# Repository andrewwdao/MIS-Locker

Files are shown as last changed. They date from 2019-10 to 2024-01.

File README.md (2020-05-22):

# SOURCE CODE FOR MIS-CTU LOCKER

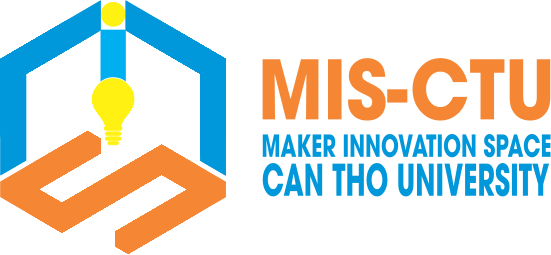
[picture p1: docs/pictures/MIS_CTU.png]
MIS-CTU logo (https://mis.ctu.edu.vn/)


System code for MIS-CTU Locker system. Designed for [Raspberry Pi](https://en.wikipedia.org/wiki/Raspberry_Pi) based devices.
Tested on Raspberry Pi 3B+.



 <!-- [![License](https://img.shields.io/github/license/minhan74/MIS-Locker.svg)](LICENSE) -->


## Documentation

* **[User guide]**: Show user on how to use the locker.
* **[Admin guide]**: Guidance for admin, how to further configurate the software, or further develop it.
* **[Software Installation]**: How to flash Rasbian and install the system.
* **[Hardware Documentation]**: Documents about PCB, electronics components,...
* **[Undergrad Thesis Report]**: A part of this project is also my undergraduate thesis, you can have a look of it here. (in Vietnamese)

## Credited libraries

* [Python3-fingerprint], (c) 2016 Bastian Raschke. Licensed under the German Free Software License
* [Adafruit CircuitPython ADS1x15], (c) 2017 Carter Nelson for Adafruit Industries. Licensed under the MIT License.
* [pySerial], (c) 2001 - 2017 Chris Liechti <cliechti@gmx.net>. Licensed under the BSD Liscense.
* [smbus],(c) 2015 - 2017 Pimoroni Ltd.
* [smbus2], (c) 2017 - 2019 Karl-Petter Lindegaard. Licensed under the MIT License.
* [RPi.GPIO], (c) 2012 - 2019 Ben Croston. Licensed under the MIT License.
* [wiringPi], (c) 2013 - 2019 Gordon <projects@drogon.net>.
* [Flask], (c) 2010 Pallets. Licensed under the BSD 3-Clause Liscense
* [WTForm], (c) 2008 by the WTForms team. Licensed under the BSD Liscense.
* [SQLAlchemy], (c) 2005 - 2020 SQLAlchemy authors and contributors. Licensed under the MIT License.
* [Flask-Migrate], (c) 2013 Miguel Grinberg. Licensed under the MIT License.
* [Flask-Bootstrap], (c) 2013 - 2019 Marc Brinkmann. Licensed under the BSD 3-Clause Liscense.
* [Readonly], (c) 2017 - 2019 Ways. Licensed under the GNU License.
* [Gevent], (c) 2015 - 2020 Denis Bilenko, Jason Madden. Licensed under the MIT License.

 _And the contribution of the huge open-source community world wide._

**Made for Maker Innovation Space, Can Tho University, Can Tho, Vietnam (MIS-CTU).**

## Sponsors

CTU small (https://ctu.edu.vn/)
MIS-CTU small (https://mis.ctu.edu.vn/)
URI small (https://sites.google.com/asu.edu/uri-coordinator-resources/uri-research-symposium/)
Konel small (https://konel.jp/)

_(c) 2019 - 2020 [Minh-An Dao] - Minh-Luan Nguyen_
_Licensed under the MIT License. All rights reserved._

<!-- Links -->
[User guide]: /docs/User_guide.md
[Admin guide]: /docs/Admin_guide.md
[Software Installation]: /docs/Installation.md
[Software Configuration]: /docs/Configuration.md
[Hardware Documentation]: /docs/Hardware-Documentation.md
[Undergrad Thesis Report]: https://bit.ly/DMA_Undergrad

[Python3-fingerprint]: https://github.com/bastianraschke/pyfingerprint
[Adafruit CircuitPython ADS1x15]: https://github.com/adafruit/Adafruit_CircuitPython_ADS1x15
[pySerial]: https://github.com/pyserial/pyserial
[smbus]: https://github.com/pimoroni/py-smbus
[smbus2]: https://github.com/kplindegaard/smbus2
[RPi.GPIO]: https://pypi.org/project/RPi.GPIO/
[wiringPi]: http://wiringpi.com/
[Flask]: https://github.com/pallets/flask
[WTForm]: https://github.com/wtforms/wtforms
[SQLAlchemy]: https://github.com/sqlalchemy/sqlalchemy
[Flask-Migrate]: https://github.com/miguelgrinberg/Flask-Migrate
[Flask-Bootstrap]: https://github.com/mbr/flask-bootstrap
[Readonly]: https://gitlab.com/larsfp/rpi-readonly
[Gevent]: https://pypi.org/project/gevent/

[Minh-An Dao]: https://bit.ly/DMA-HomePage

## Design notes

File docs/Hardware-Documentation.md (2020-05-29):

# HARDWARE DOCUMENTATION

## SOURCE FILES AND EXPLANATION

Altium files of this project can be found on [pcb folder on github]

Detailed explanation can be found on my [undergraduate thesis report] (in Vietnamese only).

This file will only cover things that haven’t been mentioned on the thesis report.

## OPTO

After a long time using (6 months – 2 years), the electric locks may start to be warmed when working. If that happens, change the OPTO will solve the problem since the IR LEDs inside the OPTO are aging and cause the FET to not working properly.

## MOSFET

This project is using the Power MOSFET IRF540N as the main switch for the 12V LEDs and 12V solenoid locks.

However, this MOSFET is not ideally designed for switching application, it’s designed for linear mode operation.

Currently in the system, it operates in linear mode, but thanks to the high current and high voltage it can endure when applying 5V Vgs, it behaves like a switch.

But obviously this is not optimized design. Therefore, for further version of this system (if any), this type of MOSFET **is not recommended**. Switching type MOSFET is recommended (i.e.: [AO3400 SOT23-3 N-1CH 5A 30V])

## Buttons and limit switches

Button and limit switches in the system is first designed for using ADC converter in order to save GPIO pins. However, there are plenty of noises exist because of the low-profile power supply that could severely impact the ADC read. Therefore, ADC has been eliminated. GPIO digital interrupt reading has been used instead for reading buttons and switches. You can check out the Altium files to better understand what we have modified.

This method works well with 01 locker open, but with more than 01 locker open, it is not good since we cannot distinguish between them. In the future version, ADC or other methods could be used to distinguish between different limit switches of different lockers, but button should still be using interrupt digital read for stability.

<!-- Links -->
[pcb folder on github]: https://github.com/minhan74/MIS-Locker/tree/master/pcb
[undergraduate thesis report]: https://bit.ly/DMA_undergrad
[AO3400 SOT23-3 N-1CH 5A 30V]: https://icdayroi.com/ao3400-sot23-3-n-1ch-5a-30v

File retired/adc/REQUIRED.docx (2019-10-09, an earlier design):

- Enable I2C (http://osoyoo.com/2016/06/01/drive-i2c-lcd-screen-with-raspberry-pi/):
  - Sudo raspi-config > 5.Interface Options > P5 I2C
- After rebooting the Pi, we need to modify the module’s config file. Type the following command in terminal: sudo nano /etc/modules Add following two lines in modules file if they do not exist: i2c-bcm2708 i2c-dev Then Type Ctrl X and Yes to save the file.
- Step 3: Step 3 – Install i2c tools Type following command in terminal: sudo apt-get update && sudo apt-get upgrade sudo apt-get install -y python3-smbus (https://raspberry-projects.com/pi/programming-in-python/i2c-programming-in-python/using-the-i2c-interface-2) i2c-tools

Pip install smbus2 (https://pypi.org/project/smbus2/)
sudo reboot

After rebooting the system, type the following command in order to check software installation:
lsmod | grep i2c_
You should see i2c_bcm2708 in a list, this means the library has been installed successfully.

- sudo i2cdetect -y 1
- You should see something as follows: 0 1 2 3 4 5 6 7 8 9 a b c d e f 00: — — — — — — — — — — — — — 10: — — — — — — — — — — — — — — — — 20: — — — — — — — — — — — — — — — — 30: — — — — — — — — — — — — — — — 27 40: — — — — — — — — — — — — — — — — 50: — — — — — — — — — — — — — — — — 60: — — — — — — — — — — — — — — — — 70: — — — — — — — —

NOW YOU CAN USE THE OUTSIDE CODE TO PLAY!

REFERENCES:

https://github.com/adafruit/Adafruit_CircuitPython_ADS1x15

https://github.com/adafruit/Adafruit_CircuitPython_BusDevice

https://learn.adafruit.com/adafruit-4-channel-adc-breakouts/python-circuitpython

https://learn.adafruit.com/raspberry-pi-analog-to-digital-converters/ads1015-slash-ads1115

We use the smbus2 i2c library, and i2c_rdwr func to achieve the desired conversion from adafruit library

https://pypi.org/project/smbus2/

https://raspberry-projects.com/pi/programming-in-python/i2c-programming-in-python/using-the-i2c-interface-2

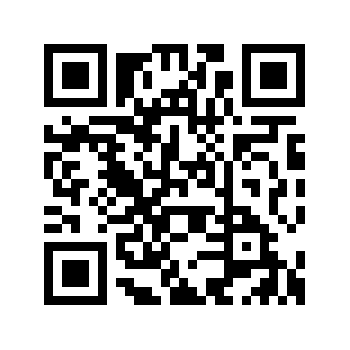
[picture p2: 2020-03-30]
docs/pictures/MISlocker-user-server.png

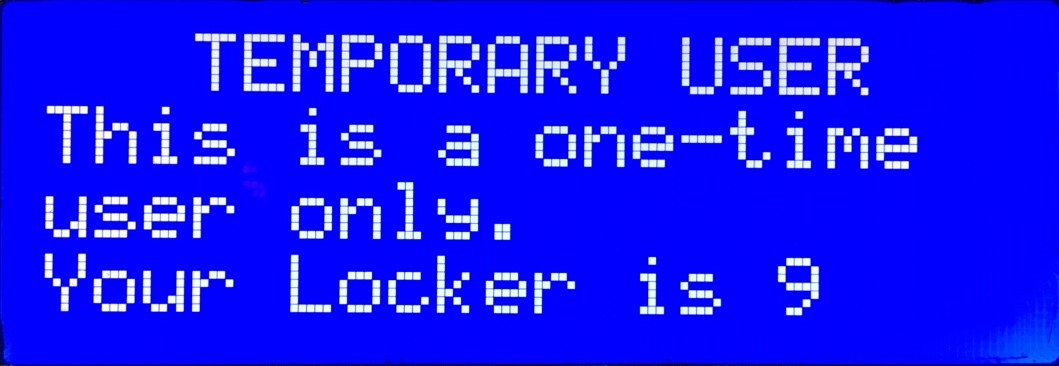
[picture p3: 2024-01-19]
docs/pictures/lcd02.jpg

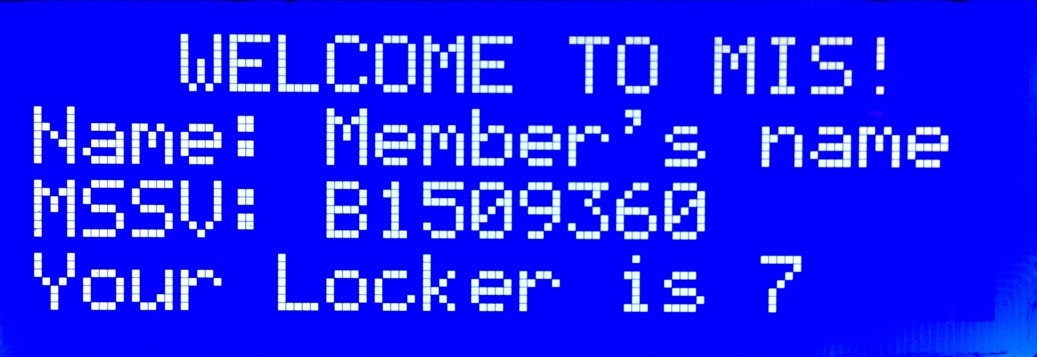
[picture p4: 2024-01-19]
docs/pictures/lcd03.jpg

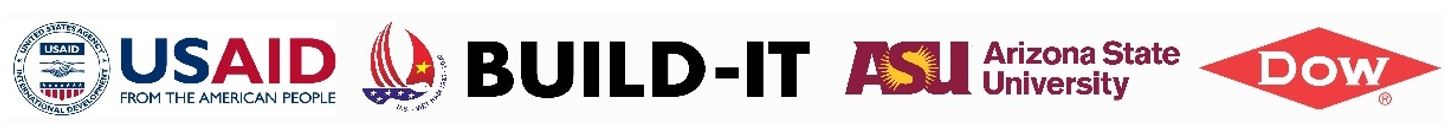
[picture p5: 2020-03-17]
docs/pictures/URI.JPG

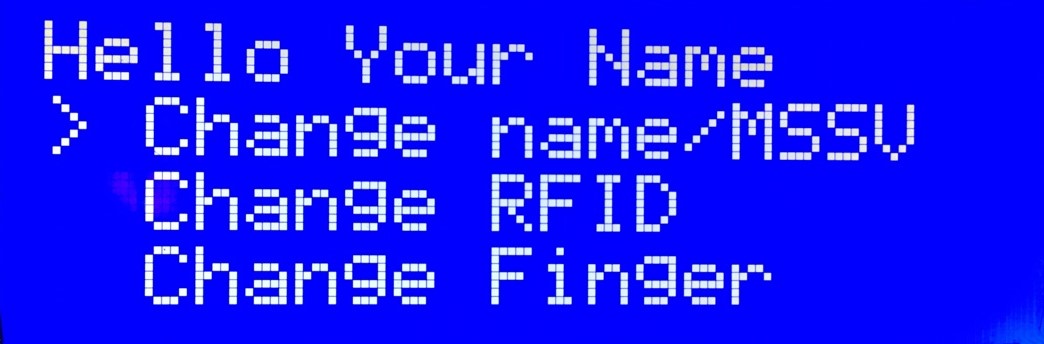
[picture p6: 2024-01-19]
docs/pictures/lcd07.jpg

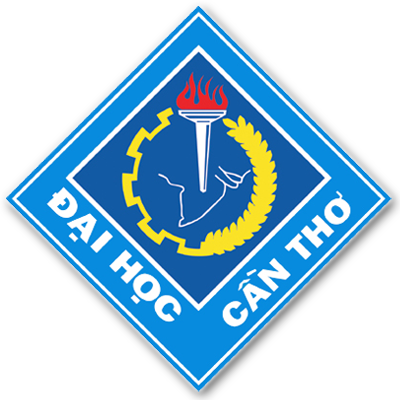
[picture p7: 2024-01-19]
docs/pictures/CTU.png

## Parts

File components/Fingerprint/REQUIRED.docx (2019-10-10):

- UART (UART to TTL → USB):
- Cài PySerial:
  - Mở file 2.Serial_setup.pdf và làm theo, nhớ xài python3 chứ kp python
  - Hoặc:
  - Sudo apt-get install python3-serial
  - Cd /boot
  - Sudo nano config.txt
  - Search for (or add new to the end of the file): enable_uart = 1
  - Reboot
  - ls /dev/tty* → liệt kê tất cả các cổng uart đang có
  - ls /dev/serial/by-* → liệt kê thông tin chi tiết của các peripherals đang cắm vào rasp
  - lsusb → liệt kê tất cả các cổng usb đang kết nối
  - Code mẫu:

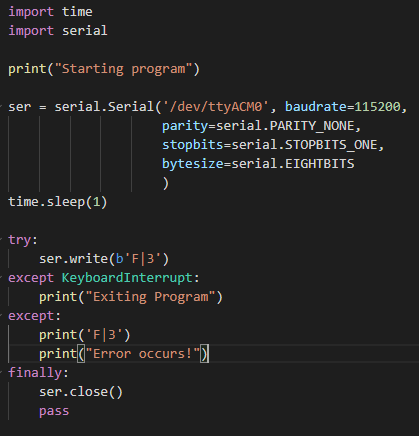
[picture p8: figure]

  - python -m serial.tools.list_ports will print a list of available ports. It is also possible to add a regexp as first argument and the list will only include entries that matched.
- https://pyserial.readthedocs.io/en/latest/shortintro.html#opening-serial-ports

The connection of both devices:

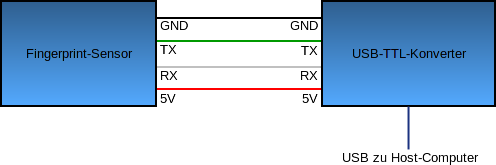
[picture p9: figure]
Connection of fingerprint sensor and converting board

We connect the power supply (red wire) to the 5V pin of the converter, the ground (black wire) to ground/GND pin. The transceiver data wire (green wire) of the sensor to the TX pin of the converter and the receiver data wire (white wire) to the RX pin.

Note: The data wires of some USB-TTL converting boards (specifically the USB-wire versions) must be connected the other way round. If no communication happen, simply try to exchange the data wires.

If you connect the fingerprint sensor via converting board with your Raspberry Pi, the device should become available via the path "/dev/ttyUSB0". For default only the root user is able to use serial devices. To make sure that the normal user (e.g. "pi") is able to use the fingerprint sensor, you have to add him to the user group "dialout":

~$ sudo usermod -a -G dialout pi

Now your have to restart your system.

NOW YOU CAN USE THE OUTSIDE CODE TO PLAY!

REFERENCES:

https://github.com/bastianraschke/pyfingerprint

https://sicherheitskritisch.de/2015/03/fingerprint-sensor-fuer-den-raspberry-pi-und-debian-linux-en/

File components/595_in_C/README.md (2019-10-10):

THIS IS THE C CODES AND C COMPILED PROGRAMS USED TO CONTROL 6 74HC595 (2 PERIPHERAL MODULES OF THE MIS LOCKER).

peripheral_init can be call directly with: ./peripheral_init

HOWEVER, peripheral_main cannot be call like that, you have to put parameters on it:

Ex: ./peripheral_main 1 2 3 4 5 6

with 1 2 3 are 3 bytes you want to give the first module, and 4 5 6 are 3 bytes you want to give the second module.

(c) Minh-An Dao 2019

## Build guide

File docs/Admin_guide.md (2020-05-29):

# ADMIN GUIDE

<span style="color: red;"><b>This current design only allows 01 door to be opened at a time!</b> </span>

## Admin Menu

There are 02 admin key: the RFID card and the RFID tag.
Usually, MIS-CTU technician will have access to the RFID tag (blue tag attached to the key of MIS-CTU). Use this tag to enter the Admin menu as followed:
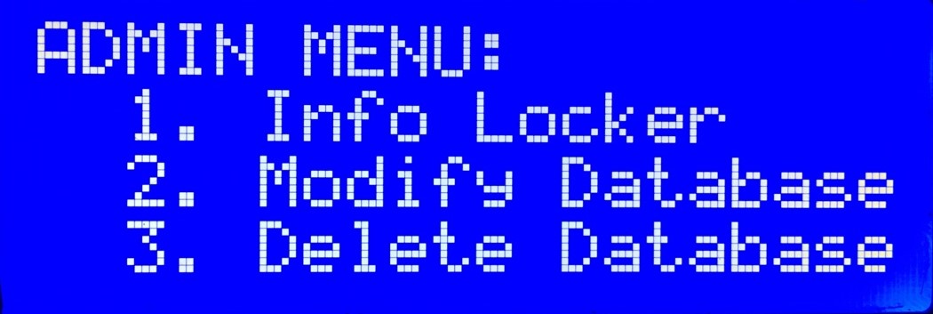
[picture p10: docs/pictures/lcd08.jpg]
Admin menu
    

* **Info Locker:** This allows admin to check locker information, and open any of them.
* **Modify Database:** This allows admin to see the system current IP and current username. With it, admin can login to the system using SSH. When logged to the system, admin can modify database or update – upgrade the system.
* **Delete Database:** This allows admin to delete database completely without having to login to the system using SSH. **Caution:** This is irreversible!

## Modify System

You can try and play with the code of the system, and hopefully upgrade it!
However, you need to keep in mind:

* C binary codes require permission to be executed. Therefore, whenever you change your code and update it from git, **ALWAYS** remember to call (/home/\<user\>/system/main):

```bash
chmod +x binary_renewer.sh
sudo ./binary_renewer.sh
```

**Caution:** If you forget to call these lines whenever you update your code, C binary won’t be given the needed permission, therefore could lead to wrong startup and MAY DESTROY the locker by overheating it.

## Database

Database is written in Flask.

After logging in to the system by SSH, move in to the main project folder (/home/\<user\>/system/main).

You can see the database file located there (database.db). This is an SQL database, so you can export it to any SQL system to modify it.

In case you want to modify the database directly within the system, you need to open Python shell:

```bash
sudo python3
```

First thing to do when entering the python shell is to import the needed libraries and create a database object:

```python
from database import Database
dtb = Database()
```

After importing database, you can modify it as you want (you can checkout functions listed in database.py). For example, to get all instance from the db:

```python
dtb.getAllUserInfo()
```

## Database Structure

In order to see or update database structure, you need to have a look at _models.py_ located in ./system/main/app. This is the current attribute of the database: _id, name, mssv, rfid, fing_.
After updating attributes to the database frame, you need to migrate it into the existed database. This is made easy by Flask Migrate:

```bash
flask db migrate -m "message explain what have you changed"
flask db upgrade
```

If you see the new database frame is not good and want to return to the previous version, you can do it by using:

```bash
flask db downgrade
```

You may need to re-create the database if something went-wrong. To do that, first check the database structure in app/models.py. Then delete old database and migration folder by going in system/main and run:

```bash
sudo rm -rf database.db
sudo rm -rf migrations/
```

Then create new database structure by using:

```bash
flask db init
flask db migrate -m "users table"
flask db upgrade
```

<span style="color: red;"><b>Note:</b> </span>
This database (SQLite) is compatible with SQL database, so it can be accessed and modified by SQL commands.
You can use sqlite3 module directly to access the database using python:

```python
import sqlite3
db = sqlite3.connect("database.db")
u = db.execute("SQL commands, ie: select * from User")
```

You can fetch all rows or 1 row at a time in the database by using

```python
u.fetchall()
u.fetchone()
```

You should remember to commit database changes and close the connection:

```python
db.commit()
db.close()
```

## Testing peripheral

In order to test the LEDs and/or the electric locks, go in:

```bash
./system/se seperate_components/595_in_C
```

If you haven’t renewed the binaries, do it by typing:

```bash
sudo make clean
sudo make peripheral_init peripheral_main
```

Then execute the main file:

```bash
sudo python3 main.py
```

By indicating which locker you want to test, you can test the LED and the lock corresponding to that locker. Remember that Green LED is on the same line with the electronics lock.

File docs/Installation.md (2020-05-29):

# INSTALLATION INSTRUCTION

- <span style="color: red;"><b>Login to MIS-CTU data drive to get the img file contain everything pre-configured, flash it to SD card using Raspberry Pi Imager or Balena Etcher. If you do this step, you can skip all the steps below.</b> </span>

- **Step 1:** download latest [Raspbian lite], flash to SD card with [Raspberry Pi Imager] or [Balena Etcher].
- **Step 2:** put the SD card to a Raspberry Pi. Connect HDMI, keyboard and boot up. Sign in with user: pi, password: raspberry
- Step 3: Config basic setting in raspi-config menu:
  - Type in command line:

    ```bash
    sudo raspi-config
    ```

  - Choose 2.Network options > N2 Wi-fi
  - Choose country, then type in Wifi SSID, Wifi password

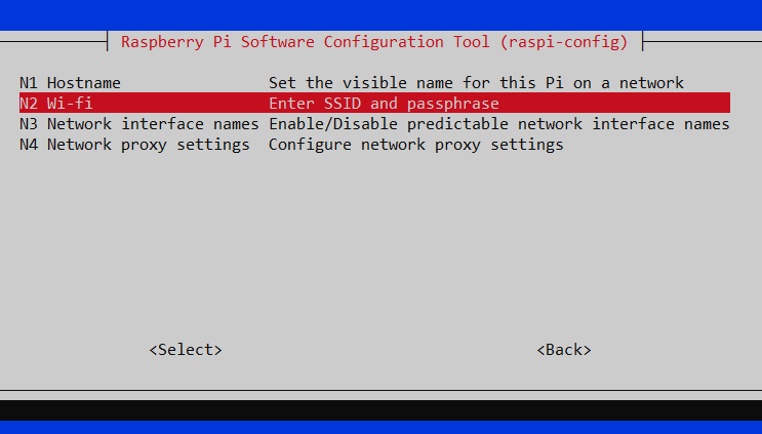
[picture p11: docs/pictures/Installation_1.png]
Step 1
    

  - Then continue to choose N4 Network proxy settings > P1 All
  - Fill in proxy setting with <http://proxy.ip:port>

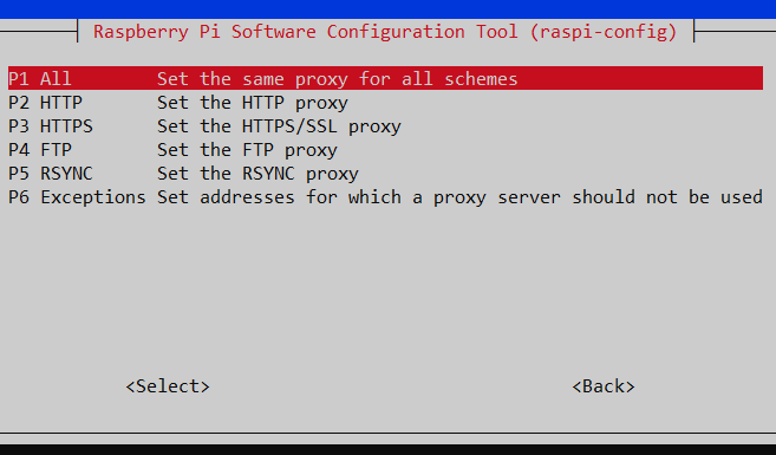
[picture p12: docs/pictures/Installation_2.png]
Step 2
    

  - Return to main menu, choose 4. Localization Options > I2 Change Timezone > Asia > Ho Chi Minh City
  - Return to main menu, choose 5. Interfacing Options > P2 SSH > Enable
  - Return to main menu, choose 5. Interfacing Options > P5 I2C > Enable
  - Return to main menu, choose 5. Interfacing Options > P6 Serial > Disable login shell to be accessible over serial (No) > Enable Serial port hardware (Yes)

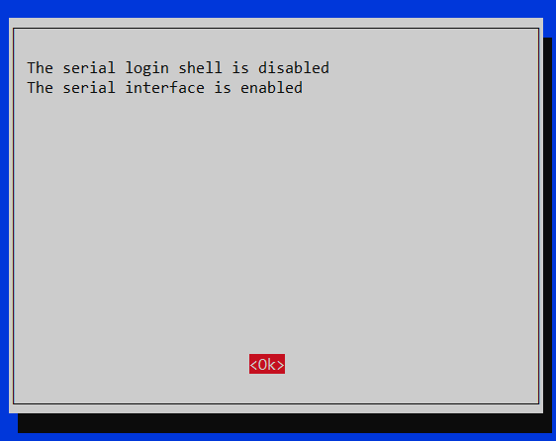
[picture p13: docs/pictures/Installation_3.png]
Step 3
    

  - Reboot to finish

- **Step 4:** Download **setup.sh** and copy it to user folder (/home/\<user\>/) of the Rasp (using WinSCP for instance).

**Caution: use Text as the Transfer type**.

**Note:** _You don’t need to copy the whole project folder, only **setup.sh** is needed._

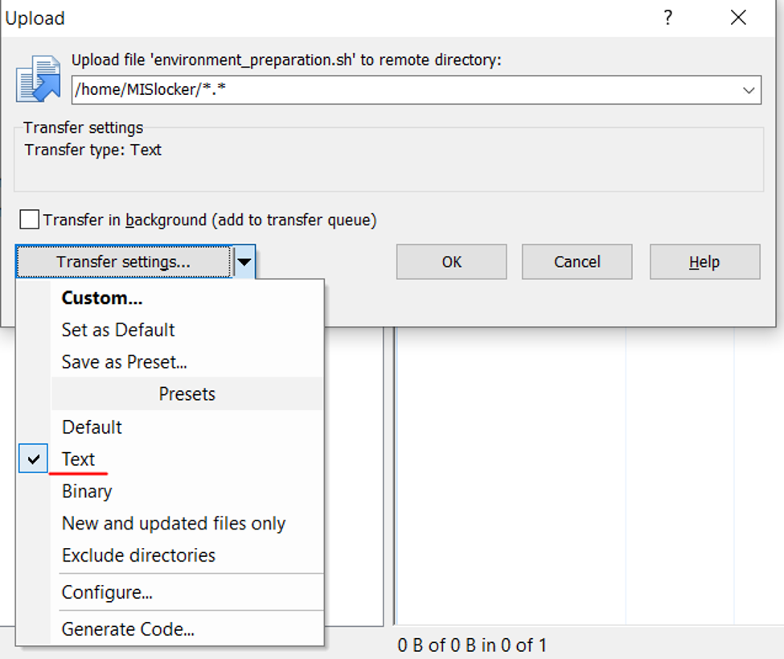
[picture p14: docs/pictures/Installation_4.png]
Step 4


- **Step 5:** to give execute permission to the setup script, open command line and type in:

```bash
chmod +x ./ setup.sh
```

- **Step 6:** run command to install the software packages:

```bash
sudo ./ setup.sh
```

**Note:** _You will need internet connected for this step._

- **Step 7:** shutdown and put the Raspberry Pi on the system PCB, put on cables and USB connection. Start up the system, log in with SSH to check working status of the device:

```bash
systemctl status MISlocker.service
systemctl status MISinit.service
```

<!-- Links -->
[Raspbian lite]: https://www.raspberrypi.org/downloads/raspbian/
[Balena Etcher]: https://www.balena.io/etcher/
[Raspberry Pi Imager]: https://www.raspberrypi.org/downloads/

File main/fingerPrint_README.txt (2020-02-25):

For admin:
In order to see information from the database within the terminal, get the terminal to this folder, 
start a python shell by typing: python3

When inside the shell, copy the below and pass in terminal to start viewing or modifying the fingerPrint sensor
(please have a look at fingerPrint.py to know which function to use)

*----start python script----*

import fingerPrint

fingerPrint.begin()
fingerPrint.activate()

*----end python script----*

now you can freely see or modify information of any member.

(c) 2020 Can Tho University

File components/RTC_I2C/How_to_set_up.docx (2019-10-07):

HOW TO (https://learn.adafruit.com/adding-a-real-time-clock-to-raspberry-pi/overview) SET UP THE DS3231 (https://www.raspberrypi-spy.co.uk/2015/05/adding-a-ds3231-real-time-clock-to-the-raspberry-pi/) AS THE HARDWARE CLOCK OF THE RASPBERRY PI

Wiring is simple:

1. Connect VCC on the breakout board to the 3.3V pin of the Pi (if using PCF8523 or DS3231)
2. Connect GND on the breakout board to the GND pin of the Pi
3. Connect SDA on the breakout board to the SDA pin of the Pi
4. Connect SCL on the breakout board to the SCL pin of the Pi

# Set up I2C on your Pi (Use the file in raspberry learned)

Verify your wiring by running

sudo apt-get install python-smbus i2c-tools

to install the helper software and then sudo i2cdetect -y 1 at the command line, you should see ID #68 show up - that's the address of the DS1307, PCF8523 or DS3231!

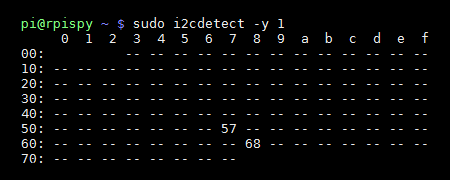
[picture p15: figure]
DS3231 RTC Module Config

# Raspbian Jessie (Systemd)

You can add support for the RTC by adding a device tree overlay. Run

sudo nano /boot/config.txt

to edit the pi configuration to the end of the file:

dtoverlay=i2c-rtc,ds3231

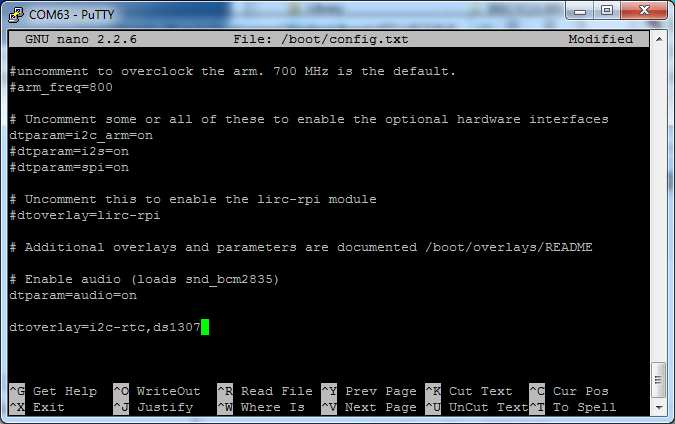
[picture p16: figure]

Save it and run sudo reboot to start again. Log in and run sudo i2cdetect -y 1 to see the UU show up where 0x68 should be

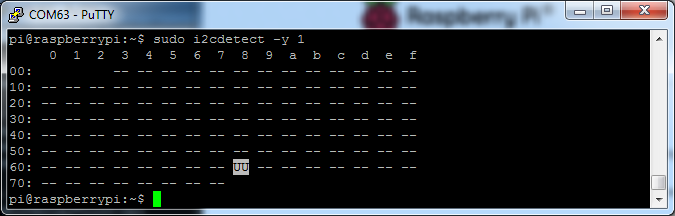
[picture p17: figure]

Disable the "fake hwclock" which interferes with the 'real' hwclock

- sudo apt-get -y remove fake-hwclock
- sudo update-rc.d -f fake-hwclock remove
- sudo systemctl disable fake-hwclock

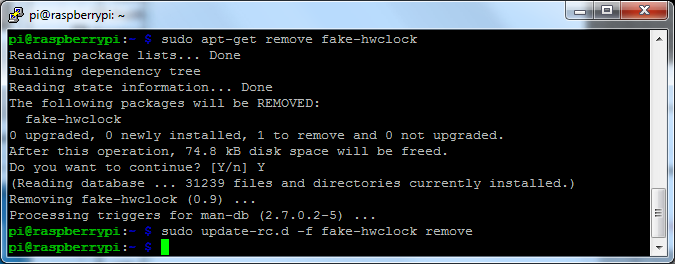
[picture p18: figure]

Now with the fake-hw clock off, you can start the original 'hardware clock' script.

Run sudo nano /lib/udev/hwclock-set and comment out these three lines:

#if [ -e /run/systemd/system ] ; then
# exit 0
#fi

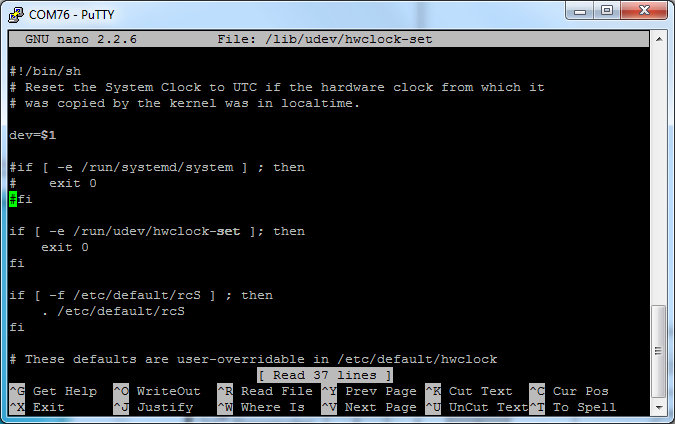
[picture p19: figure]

Also comment out the two lines

/sbin/hwclock --rtc=$dev --systz --badyear

and

/sbin/hwclock --rtc=$dev --systz

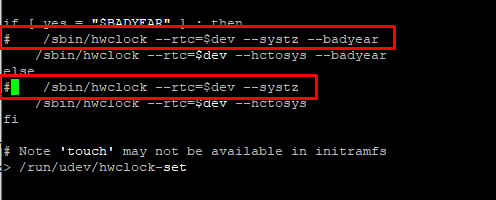
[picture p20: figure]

## Sync time from Pi to RTC

When you first plug in the RTC module, it's going to have the wrong time because it has to be set once. You can always read the time directly from the RTC with sudo hwclock -D -r

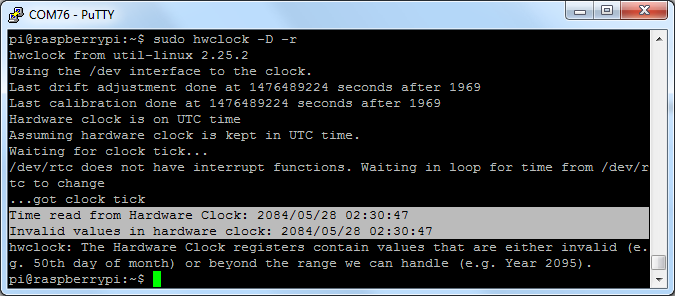
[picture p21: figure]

You can see, the date at first is invalid! You can set the correct time easily. First run date to verify the time is correct. Plug in Ethernet or WiFi to let the Pi sync the right time from the Internet. Once that's done, run sudo hwclock -w to write the time, and another sudo hwclock -r to read the time

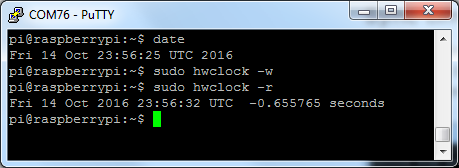
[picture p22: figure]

Once the time is set, make sure the coin cell battery is inserted so that the time is saved. You only have to set the time once

That's it! Next time you boot the time will automatically be synced from the RTC module

Now you can use the “date” command in console or

Use the the module datetime in python to call time out. (datetime.time,…)

If it cannot connect to the internet, it will use time from the RTC, if it can connect to the internet, it will use the time from the internet.

The RTC module can be removed safely when needed!

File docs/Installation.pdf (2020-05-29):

# INSTALLATION INSTRUCTION

Login to MIS-CTU data drive to get the img file contain everything pre-configured, flash it to SD card using Raspberry Pi Imager or Balena Etcher. If you do this step, you can skip all the steps below.

Step 1: download latest Raspbian lite, (https://www.raspberrypi.org/downloads/raspbian/) flash to SD card with Raspberry Pi Imager (https://www.raspberrypi.org/downloads/) or Balena Etcher. (https://www.balena.io/etcher/)
Step 2: put the SD card to a Raspberry Pi. Connect HDMI, keyboard and boot up. Sign in with user: pi, password: raspberry
Step 3: Config basic setting in raspi-config menu:

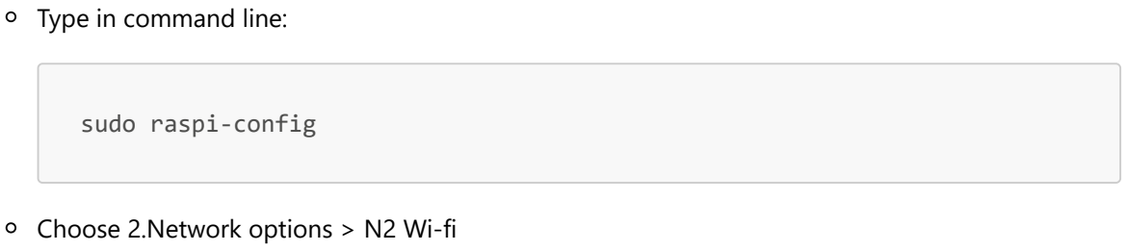
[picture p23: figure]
Type in command line:; sudo raspi-config; Choose 2.Network options > N2 Wi-fi

Choose country, then type in Wifi SSID, Wifi password

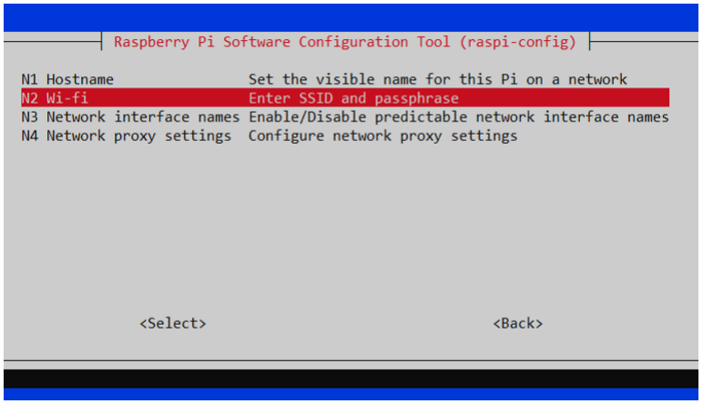
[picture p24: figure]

Then continue to choose N4 Network proxy settings > P1 All

Fill in proxy setting with http://proxy.ip:port

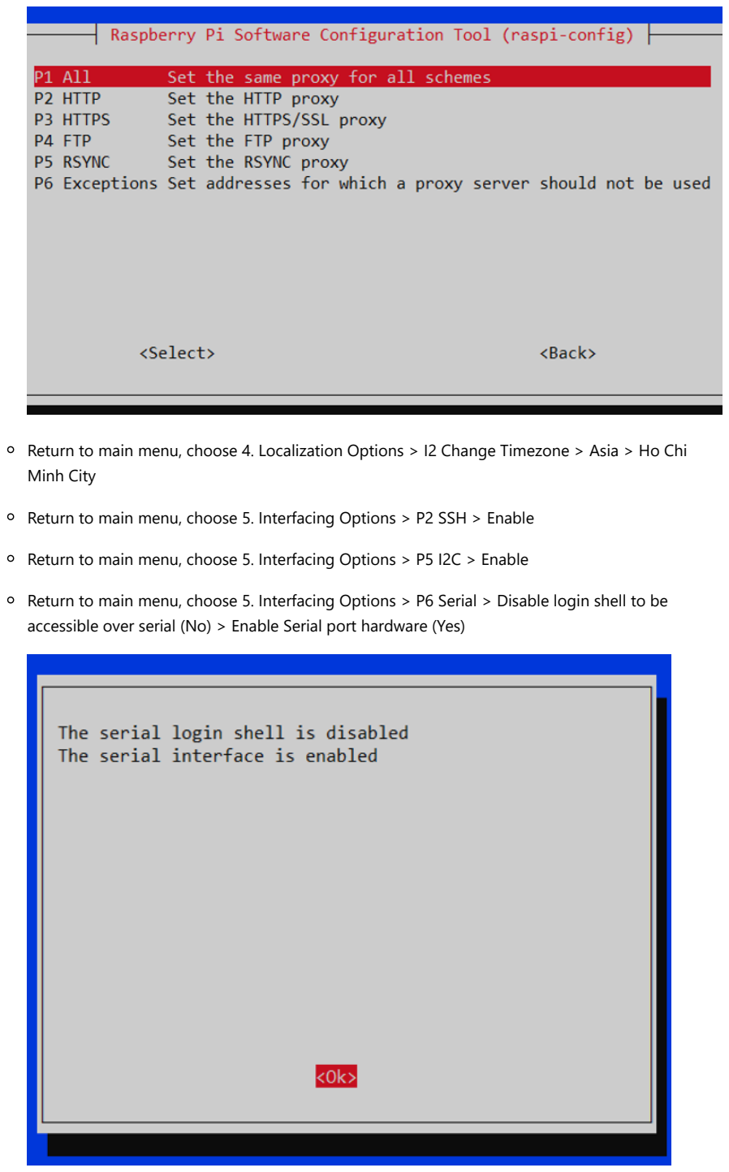
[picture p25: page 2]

Return to main menu, choose 4. Localization Options > I2 Change Timezone > Asia > Ho Chi Minh City

Return to main menu, choose 5. Interfacing Options > P2 SSH > Enable

Return to main menu, choose 5. Interfacing Options > P5 I2C > Enable

Return to main menu, choose 5. Interfacing Options > P6 Serial > Disable login shell to be accessible over serial (No) > Enable Serial port hardware (Yes)

Reboot to finish

Step 4: Download setup.sh and copy it to user folder (/home/<user>/) of the Rasp (using WinSCP for instance).

Caution: use Text as the Transfer type.

Note: You don’t need to copy the whole project folder, only setup.sh is needed.


Step 5: to give execute permission to the setup script, open command line and type in:

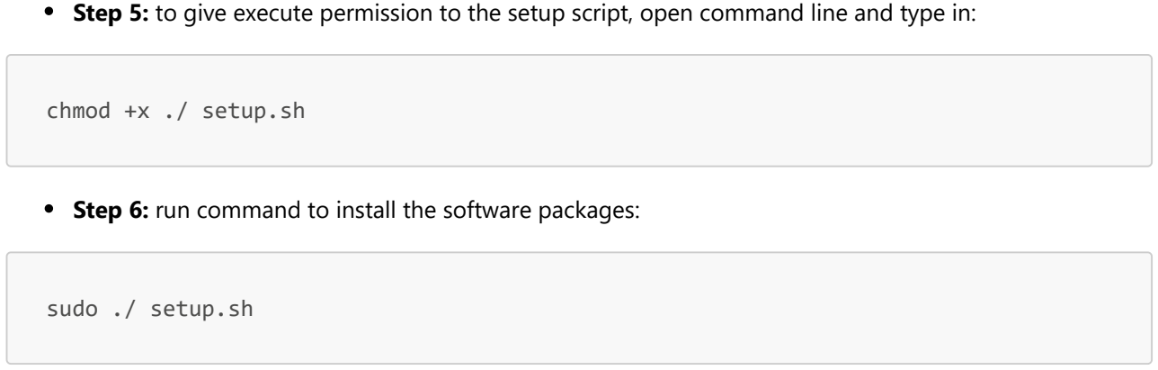
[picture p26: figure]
chmod +x ./ setup.sh; sudo ./ setup.sh

Step 6: run command to install the software packages:

Note: You will need internet connected for this step.

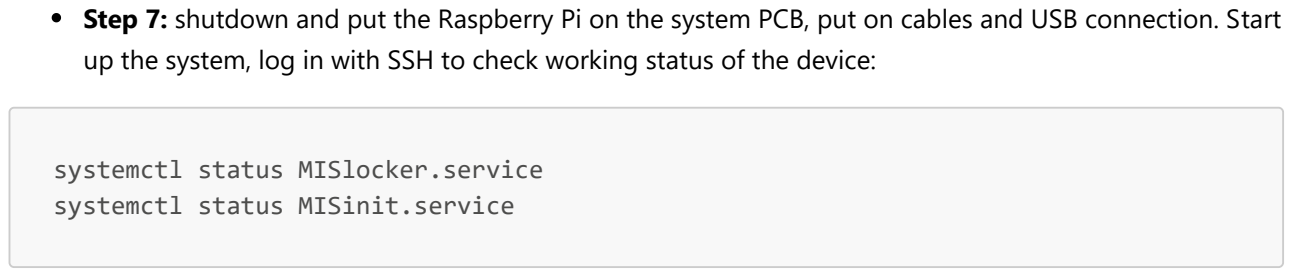
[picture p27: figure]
systemctl status MISlocker.service systemctl status MISinit.service

Step 7: shutdown and put the Raspberry Pi on the system PCB, put on cables and USB connection. Start up the system, log in with SSH to check working status of the device:

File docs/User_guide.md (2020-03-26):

<!-- User guide -->

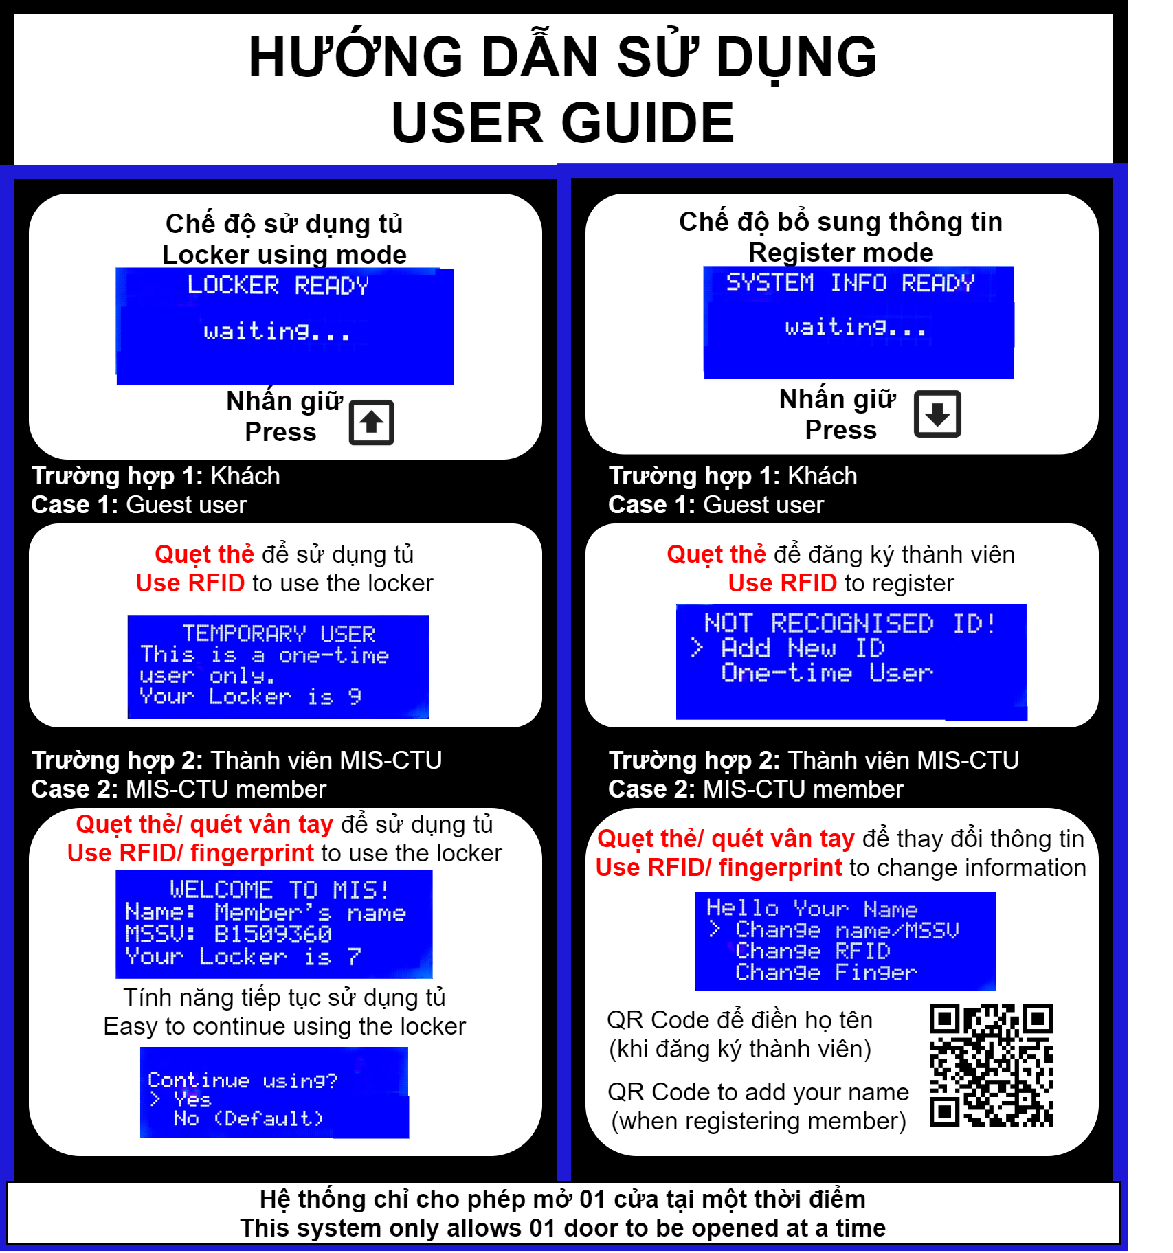
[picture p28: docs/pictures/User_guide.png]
User Guide


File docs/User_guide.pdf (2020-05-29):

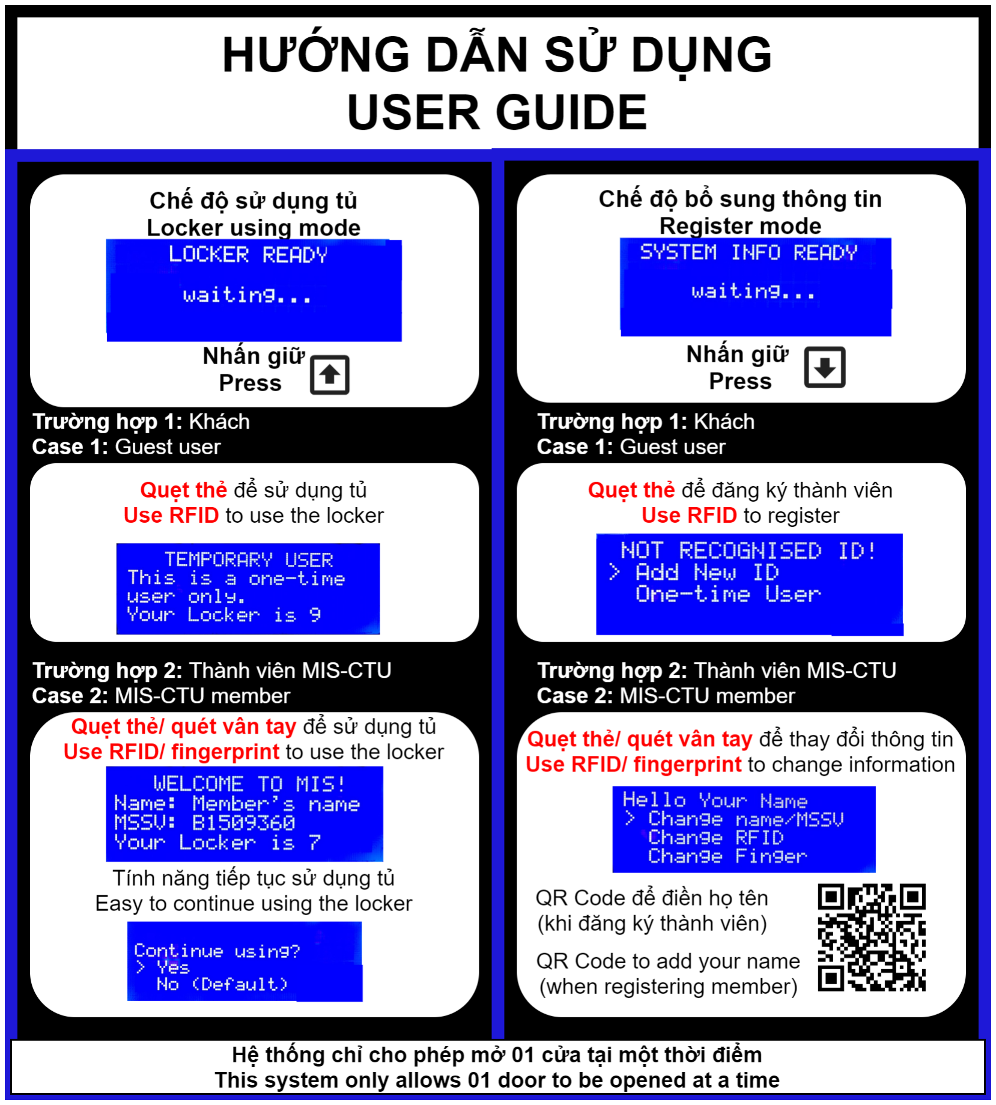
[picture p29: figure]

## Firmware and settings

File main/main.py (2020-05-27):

"""------------------------------------------------------------*-
  Main process for MISlocker
  Tested on: Raspberry Pi 3 B+
  (c) Minh-An Dao 2019 - 2020
  version 2.00 - 28/03/2020
 --------------------------------------------------------------
 *
 *
 --------------------------------------------------------------"""
import lcd
import button
import switches
from rfid import Gwiot_7304D2
from database import Database
import peripheral as pr
from datetime import datetime
import fingerPrint
import time
import buzzer as buz
import subprocess as subpro
from server import WebServer
import RPi.GPIO as GPIO  # default as BCM mode!
import signal
import os
from app.save_info.routes import shutdownServer
# ---------------------------- Configurable parameters -------------------------
# -----Admin ID key:
ADMIN_KEY = '0x47106C'
TECHNICIAN_KEY = '0x531D1B'
PROMPT_WAITING_TIME = 7 # time the lock has to wait each time user open a door 
# INFO:
# lockerArray stores the rfid ID or fingerprint ID stand with locker that has been rented (maximum 20 locker)
# Index of LockerArray is also the number of the locker.
# Therefore, lockerArray has to omit index 0!!!
# 10 lockers
lockerArray = ["NULL", None, None, None, None, None, None, None, None, None, None]
# 20 lockers
# lockerArray = ["NULL", None, None, None, None, None, None, None, None, None, None, None, None, None, None, None,
#                None, None, None, None, None]

NO_ID = 999999

SYS_MODE = False  # default mode is normal (use locker), turn true to turn to system mode (user can change their credentials)
last_second = 0   # for automatically return to locker mode
# --------------------------- Set Up ----------------------------------------
lcd.begin()
button.init()
switches.init()
rfid = Gwiot_7304D2()
dtb = Database()
pr.init()
fingerPrint.begin()
fingerPrint.activate()
server_pid = int()

# ==== ISR for cancel button when in server mode =========
def __cancelServerISR(channel):
    global button
    # incomplete member delete is handle
    print("Hello there")
    shutdownServer()
    button.reset()
    button.init()


def __wakeup_server():
    # embedded a return way before open the server
    GPIO.setmode(GPIO.BCM)
    GPIO.remove_event_detect(button.CANCEL_BUTTON)
    GPIO.add_event_detect(button.CANCEL_BUTTON, GPIO.FALLING, callback=__cancelServerISR, bouncetime=button.DEBOUNCE*2)
    # start server
    print('Server starting...')
    subpro.call(['sudo','mount','-o','remount,rw','/'], shell=False) # turn on rw
    server = WebServer()
    server.start()
    server.join() # Wait until the server thread terminates -- this is a function from the parent class Thread
    subpro.call(['sudo','mount','-o','remount,ro','/'], shell=False) # turn on ro
    # in case user don't press cancel button, reset back button
    button.reset()
    button.init()


def __shortenName(name, limit):
    name_length = len(name)
    name += ' '
    if name_length <= limit:
        return name
    else:
        name_buffer = ""
        shorten_name = name[0]
        for i in range(1, name_length):
            if name[i] == ' ':
                shorten_name += '.'
                shorten_name += name[i + 1]
                name_buffer = ""  # not the last word, reset the buffer
            else:
                name_buffer += name[i + 1]
        shorten_name += name_buffer
        return shorten_name


def __dumpDebug(iid, name, mssv, rrfid, fing):
    print('member_id: ' + str(iid))
    print('Name: ' + str(name))
    print('MSSV: ' + str(mssv))
    print('RFID: ' + str(rrfid))
    print('fingerNumber: ' + str(fing))


def __openDoorProcedure(locker):
    pr.locker_nowBusy(locker, pr.OFF)  # CLOSE RED LED stand with this LOCKER
    pr.locker(locker, pr.OPEN)  # Open locker stand with this user id

    last_millis = datetime.now().second
    while switches.read() is "ALL_CLOSED":  # if the door is not open
        # then wait
        # wait for few seconds, if no signal then automatically use 'No' command
        # or if human push ok button
        if ((datetime.now().second - last_millis) > PROMPT_WAITING_TIME) or (button.read() is "BUT_OK"):
            break

    # now the door is open!
    time.sleep(0.5)  # wait for 0.5 second before proceeding for stablization
    pr.locker(locker, pr.CLOSE)  # close locker stand with this user id

    # clean rfid and finger buffer, if existed
    rfid.flush()  # flush out old buffer before get out
    fingerPrint.flush() # clear everthing before starting
    # save the last millis
    last_millis = datetime.now().second
    # --- ask user to close the door
    lcd.waitforDoorClose()
    # --- Detect if the door is open for too long
    while switches.read() is "OPEN":  # only get out if the door is close
        # wait for few seconds, if no signal then automatically use 'No' command
        if (datetime.now().second - last_millis) > PROMPT_WAITING_TIME*5:
            buz.beep(1)
            time.sleep(0.2)

        # ------------- admin priviledge -------------------- 
        if rfid.hasID():
            current_tag = rfid.tagID()
            if current_tag == ADMIN_KEY or current_tag == TECHNICIAN_KEY:
                # switches.clean()
                pr.locker(locker, pr.CLOSE)  # close locker stand with this user id
                button.clean()
                return
        # ---------------------------------------------------
        
        # if human push ok button, THIS IS FOR DEBUG ONLY!!! SHOULD DELETE WHEN IMPLEMENT TO REAL USECASE
        # if button.read() is "BUT_OK":
        #     pr.locker(locker, pr.CLOSE)  # close locker stand with this user id
        #     return
    # --- closed
    # depend on cases the red led will be open again or not
    button.clean()
    return


def __getNextAvailableLocker():
    if None in lockerArray:  # if still have vacancy
        next_locker_available = lockerArray.index(None)
        return next_locker_available
    else:  # no vacancy left
        return None


def __waitForConfirmation():
    # time.sleep(0.4)  # prevent debounce
    while True: # wait for someone to push OK button
        if button.read() == "BUT_OK": 
            return True
        if button.read() == "BUT_CANCEL":
            return False
        


def __showAdminInfo(current_locker):
    if lockerArray[current_locker] is None:  # no info
        print(lockerArray[current_locker])
        lcd.clear()
        lcd.infoLockerNoInfoPage(current_locker)
    else:  # info existed
        current_user = lockerArray[current_locker]
        if type(current_user) is int: # a real user 
            data = dtb.getMemberInfoByID(current_user) # with get user information with user_id
            user_name = data[2]
            user_mssv = data[3]
            lcd.clear()
            lcd.infoLockerPage(__shortenName(user_name,13), user_mssv, current_locker)
        else:  # temporary user with full rfid string
            lcd.clear()
            lcd.infoLockerTempPage(current_locker)


def __ChangeName(user_id):
    # Add personal information
    lcd.clear()
    lcd.confirmChangeInfo()

    # wait for confirm or cancel
    while True:
        button_state = button.read()
        if button_state == "BUT_OK": 
            break # continue to our program
        if button_state == "BUT_CANCEL":
            return # do not do anything
    

    # log old user name and mssv before replace with temporary one for not getting same mssv
    old_data = dtb.getMemberInfoByID(user_id)
    old_user_name = old_data[2]
    old_user_mssv = old_data[3]
    dtb.changeInfo(user_id, 'user name', 'B0000000') # dumb data for temporary
    
    # Create dumb user in the database
    dtb.addDumbUser()

    lcd.clear()
    lcd.changeNameMSSV()

    __wakeup_server()  # run collecting app

    # get info from server and then delete the incomplete user
    data = dtb.getLastMemberInfo() # incomplete user deleter already integrated - wake up server MUST go through this filter
    
    # below code are imune with incomplete user deleter, since it will have name and mssv
    user_valid = data[0]
    if user_valid:
        temp_user_id  = data[1]
        new_user_name = data[2]
        new_user_mssv = data[3]
        dtb.delMember(temp_user_id)
    else: # if user cancel in the middle of the logging, then return the old information
        new_user_name = old_user_name
        new_user_mssv = old_user_mssv
    
    # make change to the database
    dtb.changeInfo(user_id, new_user_name, new_user_mssv)

    # incomplete user due to cancelation of user is already delete above

    return


def __addRFID():
    lcd.clear()
    rfid.flush()  # clear everything before starting
    fingerPrint.flush() # clear everthing before starting
    while True:
        lcd.addRFIDPage()
        # wait for signal here
        if rfid.hasID():
            current_tag = rfid.tagID()
            [status, user_id] = dtb.addRFID(current_tag) # add rfid to database and return the user id from dtb
            if status:  # RFID added
                lcd.clear()
                lcd.addRFIDSuccessPage()
                __waitForConfirmation()
                return [True, user_id]
            else:  # RFID existed
                lcd.clear()
                lcd.addRFIDFailPage()
                choosing_pointer = 1  # default at first position
                lcd.pointerPos(2, choosing_pointer)
                # ------------------Button part ------------------
                while True:
                    status = button.read()
                    if status is "BUT_OK":
                        if choosing_pointer == 1:  # retry
                            lcd.clear()
                            rfid.flush()  # clear everything before starting
                            fingerPrint.flush() # clear everthing before starting
                            break
                        elif choosing_pointer == 2: # cancel
                            # clean rfid and finger buffer, if existed
                            rfid.flush()  # flush out old buffer before get out
                            fingerPrint.flush() # clear everthing before starting
                            return [False, NO_ID]
                        return [False, NO_ID]
                    elif status is "BUT_CANCEL":
                        # clean rfid and finger buffer, if existed
                        rfid.flush()  # flush out old buffer before get out
                        fingerPrint.flush() # clear everthing before starting
                        return [False, NO_ID]
                    elif status is "BUT_UP":
                        if choosing_pointer == 1:  # limit to 1
                            pass
                        else:
                            choosing_pointer -= 1
                        lcd.addRFIDFailPage()
                        lcd.pointerPos(2, choosing_pointer)
                    elif status is "BUT_DOWN":
                        if choosing_pointer == 2:  # limit to 2
                            pass
                        else:
                            choosing_pointer += 1
                        lcd.addRFIDFailPage()
                        lcd.pointerPos(2, choosing_pointer)

        # At anytime, if cancel was pressed, cancel the whole process
        if button.read() is "BUT_CANCEL":
            return [False, NO_ID]


def __ChangeRFID(user_id):
    lcd.clear()
    rfid.flush()  # clear everything before starting
    fingerPrint.flush() # clear everthing before starting
    while True:
        lcd.changeRFIDPage()
        # wait for signal here
        if rfid.hasID():
            current_tag = rfid.tagID()
            if dtb.searchRFID(current_tag)[0]:
                lcd.clear()
                lcd.changeRFIDExistedPage()
                __waitForConfirmation()
                return False
            else:
                status = dtb.changeRFID(user_id, current_tag) # add rfid to database and return the user id from dtb
                if status:  # RFID change successfully
                    lcd.clear()
                    lcd.changeRFIDSuccessPage()
                    __waitForConfirmation()
                    return True
                else:  # RFID failed to change
                    lcd.clear()
                    lcd.changeRFIDFailPage()
                    choosing_pointer = 1  # default at first position
                    lcd.pointerPos(2, choosing_pointer)
                    # ------------------Button part ------------------
                    while True:
                        status = button.read()
                        if status is "BUT_OK":
                            if choosing_pointer == 1:  # retry
                                lcd.clear()
                                rfid.flush()  # clear everything before starting
                                fingerPrint.flush() # clear everthing before starting
                                break
                            elif choosing_pointer == 2: # cancel
                                # clean rfid and finger buffer, if existed
                                rfid.flush()  # flush out old buffer before get out
                                fingerPrint.flush() # clear everthing before starting
                                return False
                            return False
                        elif status is "BUT_CANCEL":
                            # clean rfid and finger buffer, if existed
                            rfid.flush()  # flush out old buffer before get out
                            fingerPrint.flush() # clear everthing before starting
                            return False
                        elif status is "BUT_UP":
                            if choosing_pointer == 1:  # limit to 1
                                pass
                            else:
                                choosing_pointer -= 1
                            lcd.changeRFIDFailPage()
                            lcd.pointerPos(2, choosing_pointer)
                        elif status is "BUT_DOWN":
                            if choosing_pointer == 2:  # limit to 2
                                pass
                            else:
                                choosing_pointer += 1
                            lcd.changeRFIDFailPage()
                            lcd.pointerPos(2, choosing_pointer)

        # At anytime, if cancel was pressed, cancel the whole process
        if button.read() is "BUT_CANCEL":
            return False
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

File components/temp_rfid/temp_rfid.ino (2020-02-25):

/*------------------------------------------------------------*-
  RFID125Khz sender - MASTER FILE
  (c) An Minh Dao 2019
  version 1.00 - 27/11/2019
---------------------------------------------------------------
*
* REMEMBER to define in c_cpp_properties.json as well
* 
--------------------------------------------------------------*/
#include "RFID_125Khz.h"

void setup() {
  Serial.begin(115200);
  RFID125_init();
  pinMode(LED_BUILTIN, OUTPUT);
  digitalWrite(LED_BUILTIN,HIGH);
  // Serial.println("System Ready!");
}

void loop() {
  if (hasID()) {
    Serial.print(getID());
    Serial.print("\r\n");
  }//end if
}

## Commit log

2019-10-07 add LICENSE and fix README
    [fingerPrint.py, pyfingerprint.py]
2019-10-08 add ADC module. working properly with smbus2. Not create finish class yet
2019-10-08 add adc.py, need to test soon
2019-10-09 added ADC usecase - need to calibrate when return to VN
2019-10-09 add fingerPrint usecases. Tested
2019-10-09 add required word file for fingerprint module
2019-10-10 combined LCD and ADC
2019-10-10 add more case for C code hc595. still testing
2019-10-11 add interrupt to fingerPrint code
2019-10-11 added fingerPrint with 595. Works fine, but the touch sensor is a little bit not good
2019-10-14 fixed JSON database. Now encrypted!
    [main.py]
2019-10-19 configure css file and fix some small bugs
    [main.py]
2019-10-19 add shutdown button in index.html
2019-10-24 add rfid and fix 404 html
    [main.py, rfid.py]
2019-10-25 fix syntax for default values
    [rfid_wiegand.c]
2019-10-25 fix some small bugs on c files and add python driven files
    [main.py, rfid.py, rfid_wiegand.c]
2019-10-25 fix python file to show up messsage from c
    [main.py]
2019-10-25 fix C a little bit to stop pausing
    [rfid.py, rfid_wiegand.c]
2019-10-25 fix little syntax bug
    [rfid.py]
2019-10-25 fix shell waiting time and add string conversion
    [ContinuousStreamRead.py, rfid.py]
2019-10-25 fix shell waiting time
    [rfid.py]
2019-10-25 change pin for compatible with pcb
2019-10-28 add buzzer C functions and fix pins corresponding to PCB
    [Rasp_HC595.c, buzzer_main.c, fingerPrint.py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]
2019-10-28 fix buzzer functions and libs
    [buzzer_main.c]
2019-10-28 fix delay and beep times
    [buzzer_main.c]
2019-10-28 add python files for buzzer
    [main.py]
2019-11-24 add ip and add readRaw for adc
2019-11-25 fix ip address for server
    [lcd.py]
2019-11-26 add interrupt for rfid rdm6300
2019-11-26 fix syntax for new class
    [main.py]
2019-11-26 fix new port for fingerprint sensor
    [fingerPrint.py, pyrfid.py, rfid.py]
2019-11-26 add finger testing main for the main folder
2019-11-26 add change pin for buttons
2019-11-26 change adc value for buttons
2019-11-28 next working step - done admin case
2019-11-28 first running version. Modified peripheral controlling. No fingerPrint yet
2020-02-19 on the way to add fingerPrint to the system, still having problem with data display and database extraction
    [fingerPrint.py, lcd.py, main.py]
2020-02-20 fix syntax error for data recognization and add delete All function for fingerPrint data
    [fingerPrint.py, main.py]
2020-02-20 add fingerprint recognition to starting screen. NO test yet!
2020-02-24 add fingerprint README, buzzer functions and almost complete fingerprint usecase
    [adc.py, buzzer_main.c, fingerPrint.py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]
2020-02-24 change millis functions
2020-02-24 add fingerprint flush to eliminate fraud detection
2020-02-24 change limit switches approaching method, add it to main
2020-02-25 added change name, rfid and fingerprint functions to the system. Works as intended
2020-02-25 add delete database function for admin, fix some typos
    [fingerPrint.py, lcd.py, main.py]
2020-02-25 add preventing press wrong option on changing information
    [lcd.py, main.py]
2020-02-26 fix some orders in no user info case
    [lcd.py, main.py]
2020-02-28 update frame for docs
2020-03-12 fix ~ to |
    [peripheral.py]
2020-03-15 update exception for i/o error
    [main.py]
2020-03-15 update shorter service and remove signal package to main
    [main.py]
2020-03-15 remove exception for stream reading, replace with silence shutdown instead
    [ContinuousStreamRead.py, main.py]
2020-03-15 update preparation shell code for fingerprint packages installation directly from pip, skip the wheel chanel in the past
2020-03-16 update database frame and add obj folder
2020-03-18 arrange frame and at github to about
2020-03-18 try to find error
    [main.py]
2020-03-18 clean up, fix typos and remove direct shell script for controlling peripheral
    [main.py, peripheral.py, rfid.py]
2020-03-22 figure out raw value for module1 limit switches
2020-03-22 update port adc for limit switches
2020-03-22 update adc switches
2020-03-22 update algorithm for switches
2020-03-22 fix algorithm for switches
    [adc.py]
2020-03-22 clean up and update adc value
2020-03-23 debugging adc
2020-03-23 update adc component
2020-03-27 testing button without adc
2020-03-27 testing button without class
2020-03-27 update new mechanism for button and switches
2020-03-27 update new isr for switches
2020-03-27 updating new method for button and switches reading
2020-03-27 updating button and switches
2020-03-27 update hardware documentation
    [FET_M1.SchDoc, FET_M2.SchDoc, GPIO_M1.SchDoc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]
2020-03-29 terminate server thread when shutdown
2020-03-29 kill the thread that are hosting server
2020-03-29 try new approach with server pid
2020-03-29 add clean up button and change fingerprint message
2020-03-29 add admin case to wait for door
2020-03-29 try new method to read switches
2020-03-29 change switches logic
2020-03-29 change switches algorithm
2020-03-30 add delete mechanism for fingerprint dtb
2020-05-05 fix existed RFID changing
    [lcd.py, main.py]
2020-05-05 try to get app pid
2020-05-05 try to access thread id
2020-05-05 try to stop server from button
2020-05-29 update database frame

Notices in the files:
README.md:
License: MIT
